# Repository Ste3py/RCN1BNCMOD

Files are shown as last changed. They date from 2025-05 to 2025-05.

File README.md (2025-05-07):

# RCN1BNCMOD

This project is about replacing the original antenna with a BNC connector on the DJI RCN1 (not tested on RCN3).



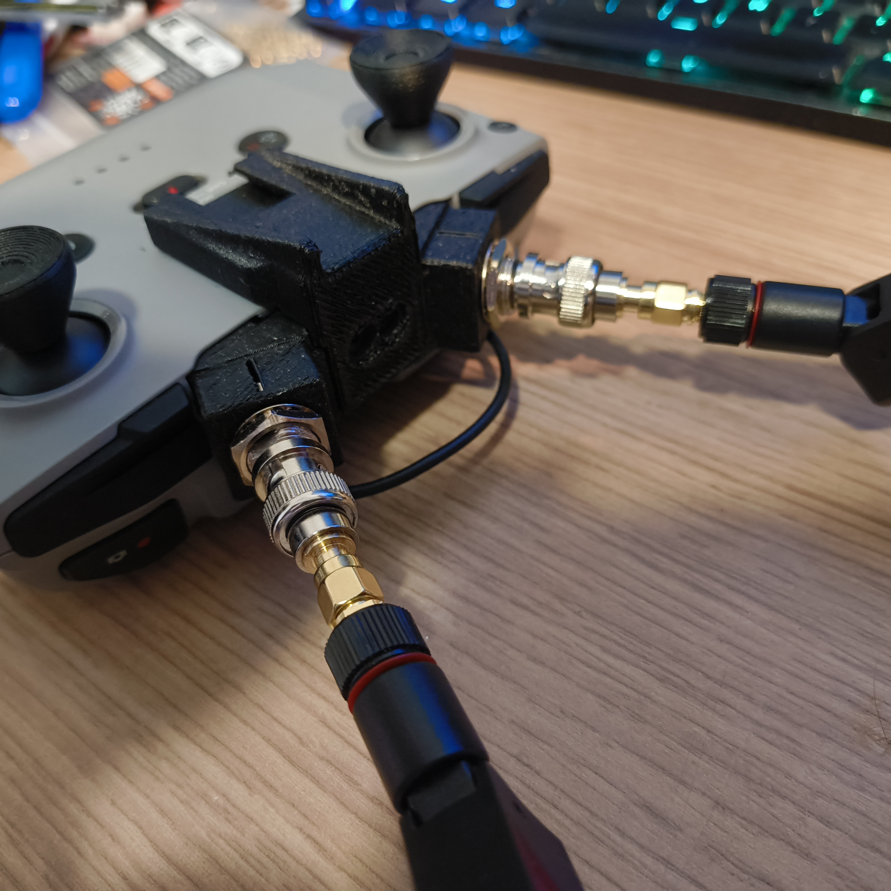
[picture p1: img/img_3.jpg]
RCN1_1
 
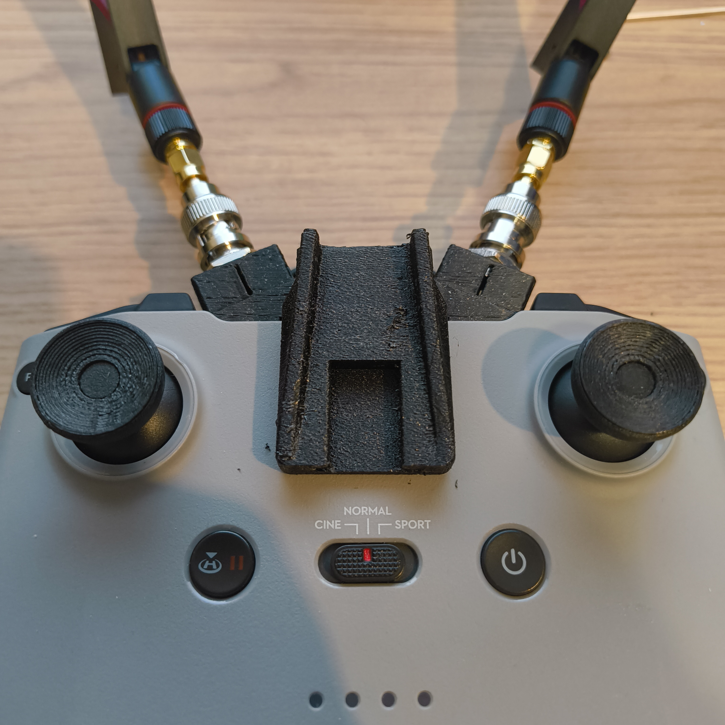
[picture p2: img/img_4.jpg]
RCN1_2


Parts needed (no Affiliate links) :
- [Cable](https://aliexpress.com/item/1005003822770662.html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)
- [tools](https://www.ifixit.com/fr-fr/products/pro-tech-go-toolkit)
- [Heated inserts M3*4mm](https://www.ruthex.de/en/collections/gewindeeinsatze/products/ruthex-gewindeeinsatz-m3-100-stuck-made-for-voron-rx-m3x5x4-messing-gewindebuchsen-fur-3d-druck)
- [M3*5 FLat head screws (7)](https://aliexpress.com/item/1005007798633538.html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)
- Filament (any filament is fine, but I recommend PETG or PETG-CF)
- a 3D Printer
- a Drill
- a 2.8mm drill bit

Antenna Side 
- [BNC Male to RP SMA](https://aliexpress.com/item/1005007758452385.html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)
- [Antenna](https://alfa-network.eu/apa-m25) (Any Wi-Fi antenna should work — just make sure it supports both 2.4 GHz and 5.8 GHz bands)

🛑 Disclaimer:
I won’t cover how to open the RCN1 here, because disassembly will void your warranty.
However, I will show you how to install the mod once it’s open.

1️⃣ Once the controller is open, disconnect the joysticks.

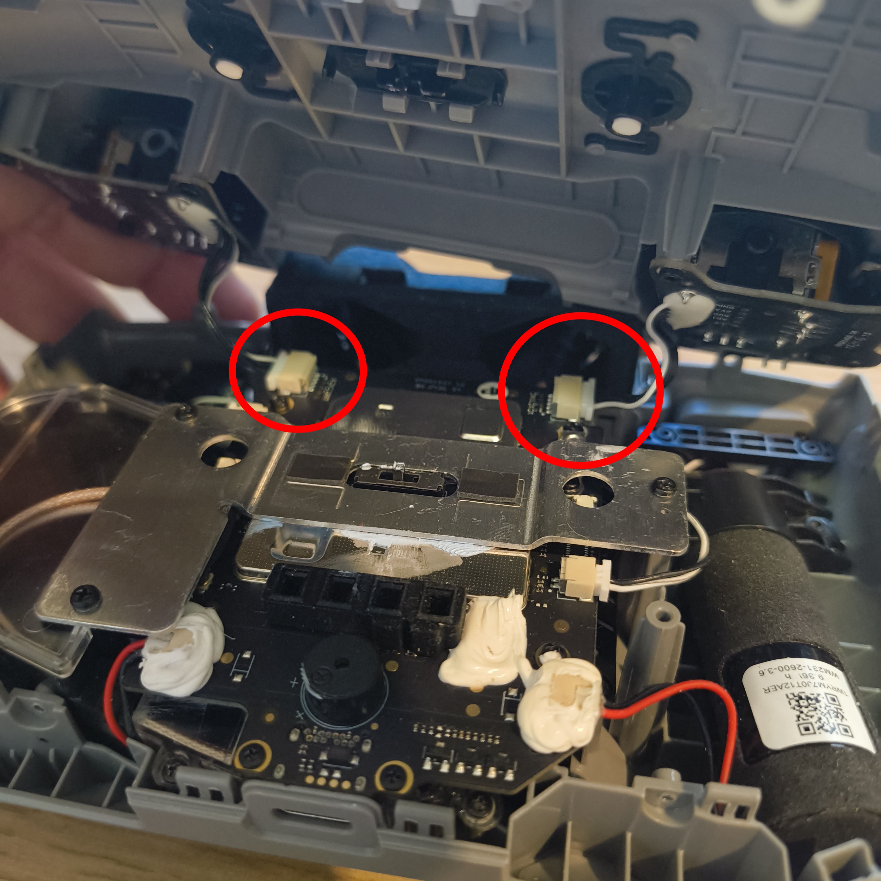
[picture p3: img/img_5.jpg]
RCN1JOYSTICK


2️⃣ Unscrew these three screws.

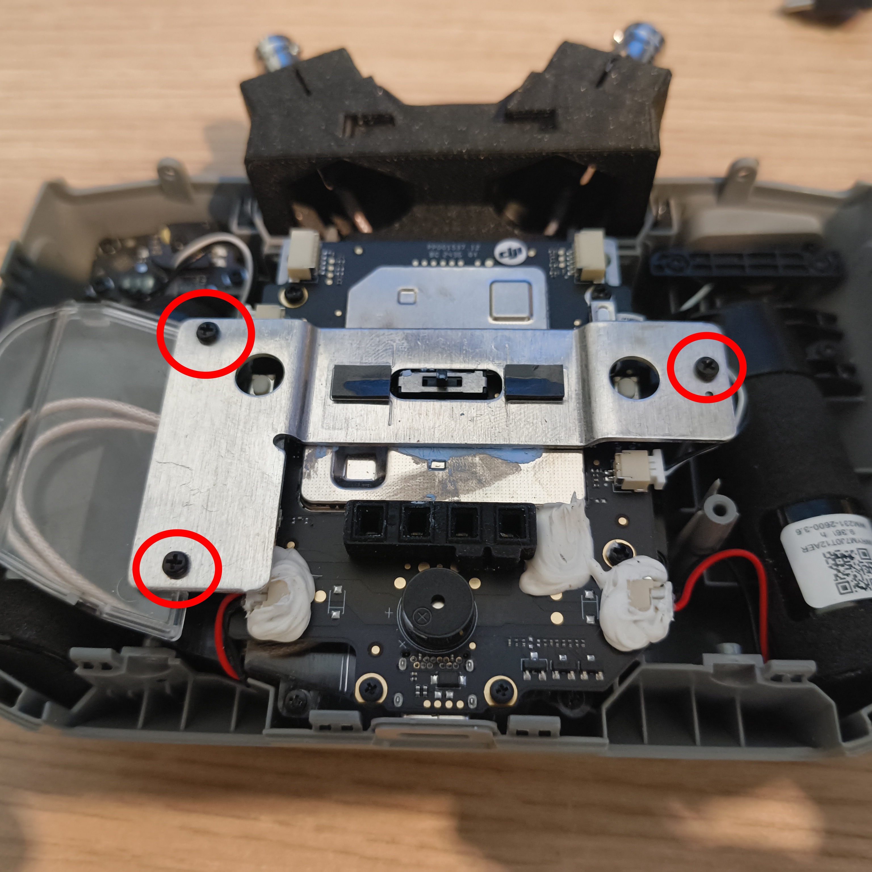
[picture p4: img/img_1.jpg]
RCN1screw


3️⃣ You now have access to the PCB.
(Ignore the modded state of my controller. I’ve already done the mod and don’t have a second RCN1 to show from scratch. The process is the same.)
Disconnect all connectors and remove the screws.
Remove the batteries first.
Be careful with the flex connector under the cage.

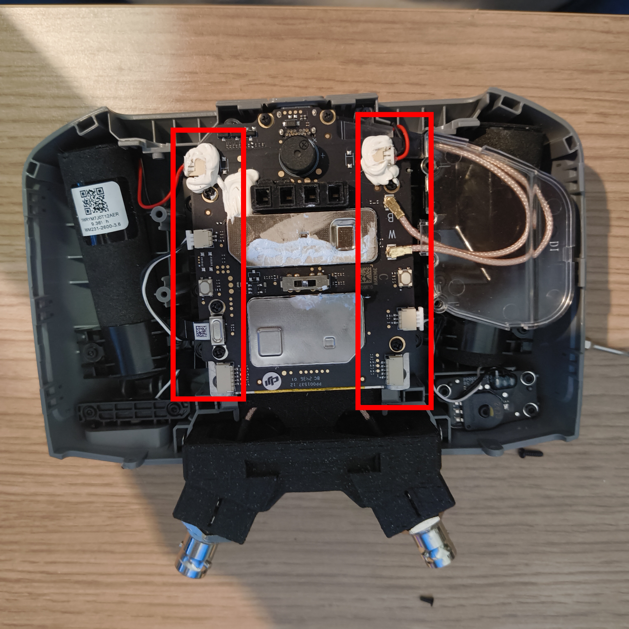
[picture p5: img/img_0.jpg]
RCN1MB


4️⃣ Remove the motherboard.
Then unscrew these two screws and remove the two transparent parts.

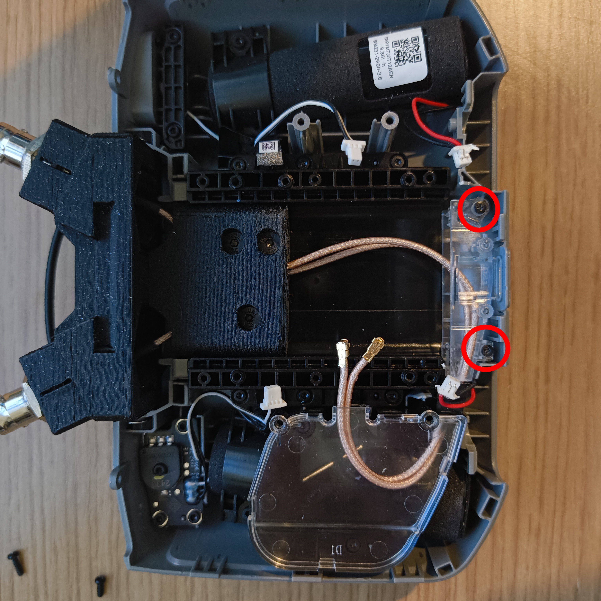
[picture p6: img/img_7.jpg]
RCN1COVER


At this point, your setup should look similar to mine, except you'll still have the original antenna attached.

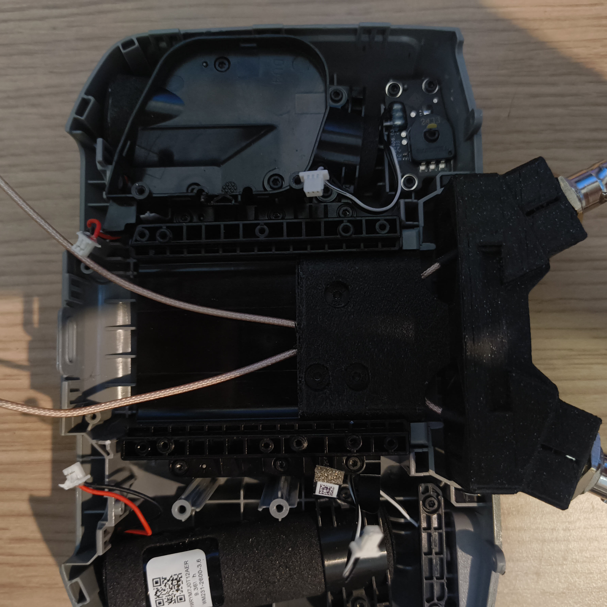
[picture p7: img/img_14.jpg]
RCN1naked


5️⃣ Remove the antenna holder by unscrewing these six screws.

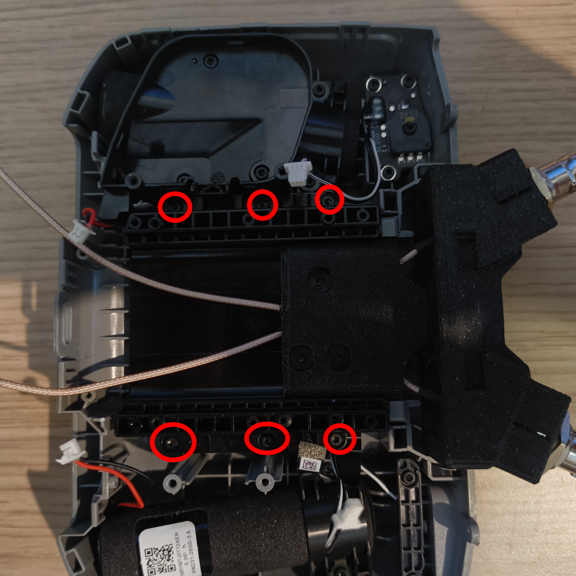
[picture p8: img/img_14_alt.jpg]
RCN1nakedalt


Now you have this piece out:

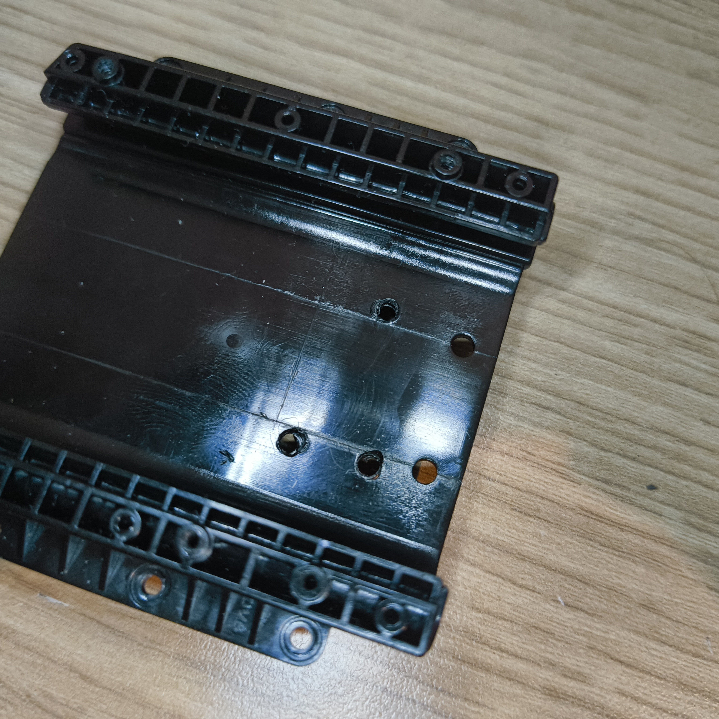
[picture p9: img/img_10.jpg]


Place it back **without screwing it in**.

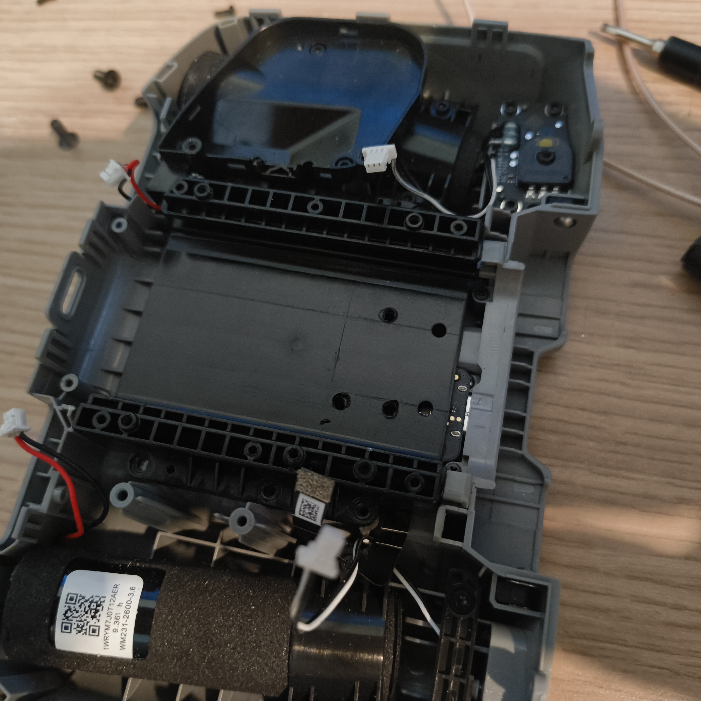
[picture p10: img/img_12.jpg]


**Assembling the BNC Connector**
6️⃣ Install the heated insert into the main part, then mount the BNC connector.

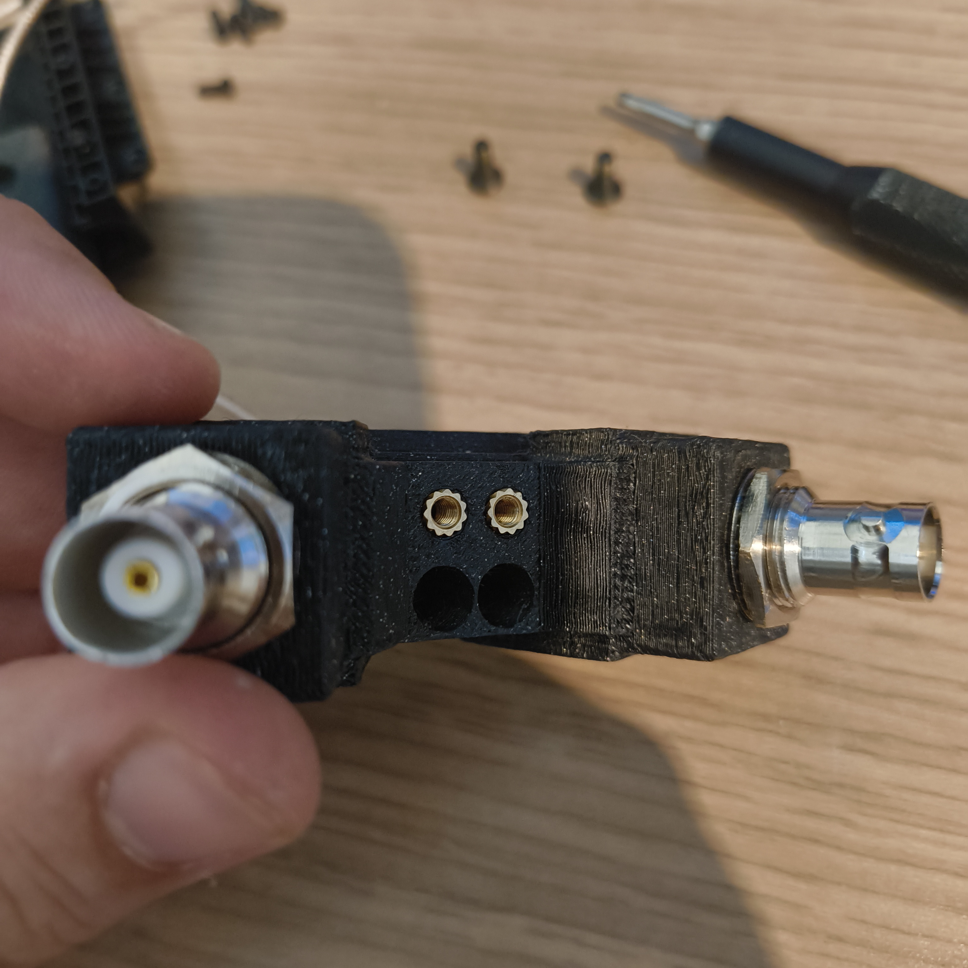
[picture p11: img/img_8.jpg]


7️⃣ On the internal support, install the heated insert and pass the cables through the holes.
It’s a bit tedious, but there’s enough space. Just be gentle to avoid damaging the connectors.

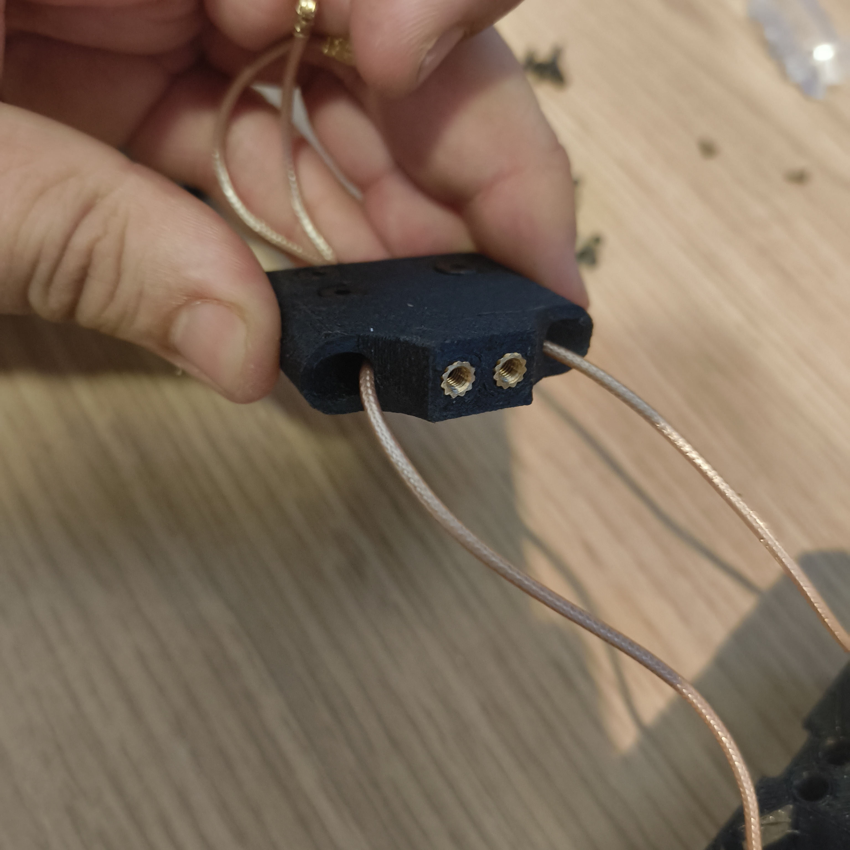
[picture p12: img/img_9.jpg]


8️⃣ Assemble both parts using two M3*5 screws in these holes.

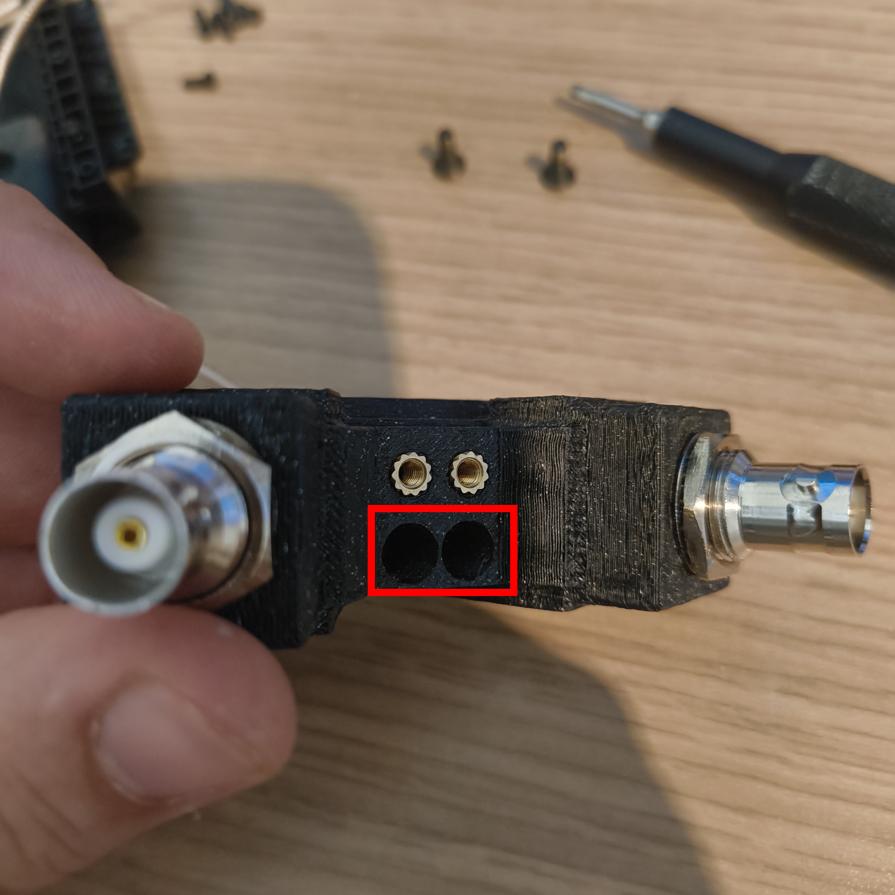
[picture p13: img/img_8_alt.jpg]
RCN1BNC2


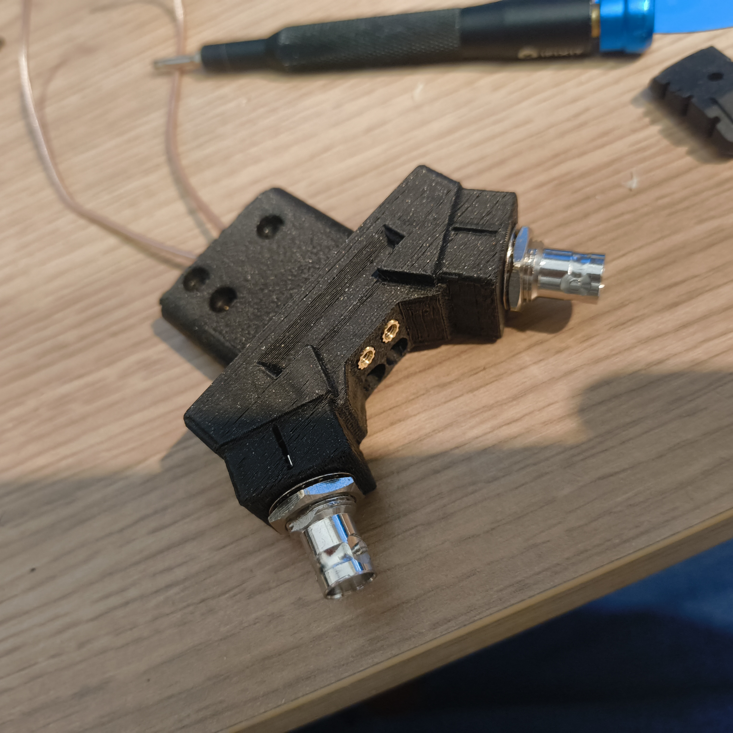
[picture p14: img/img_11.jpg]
RCN1BNC3


9️⃣ Slide the BNC assembly into the holder.

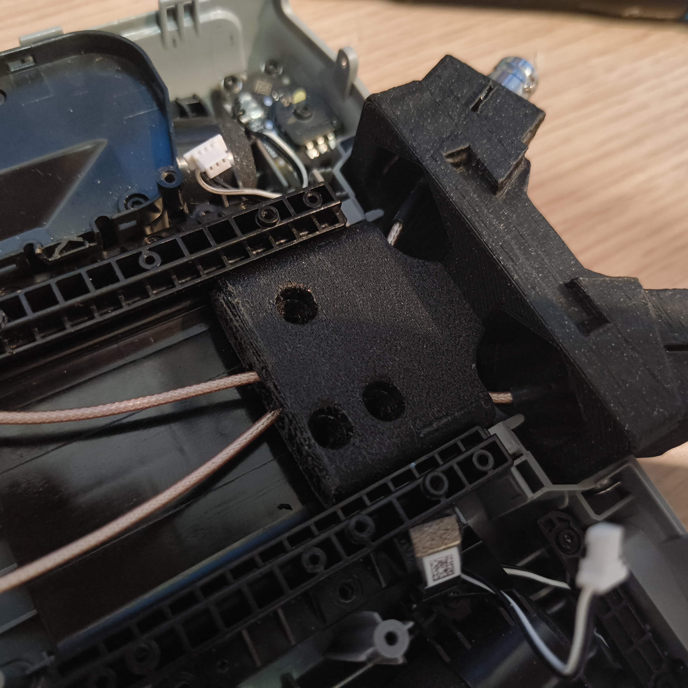
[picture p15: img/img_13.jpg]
RCN1BNC4


🔟 Mark the three small holes using the 2.8mm drill bit by hand.

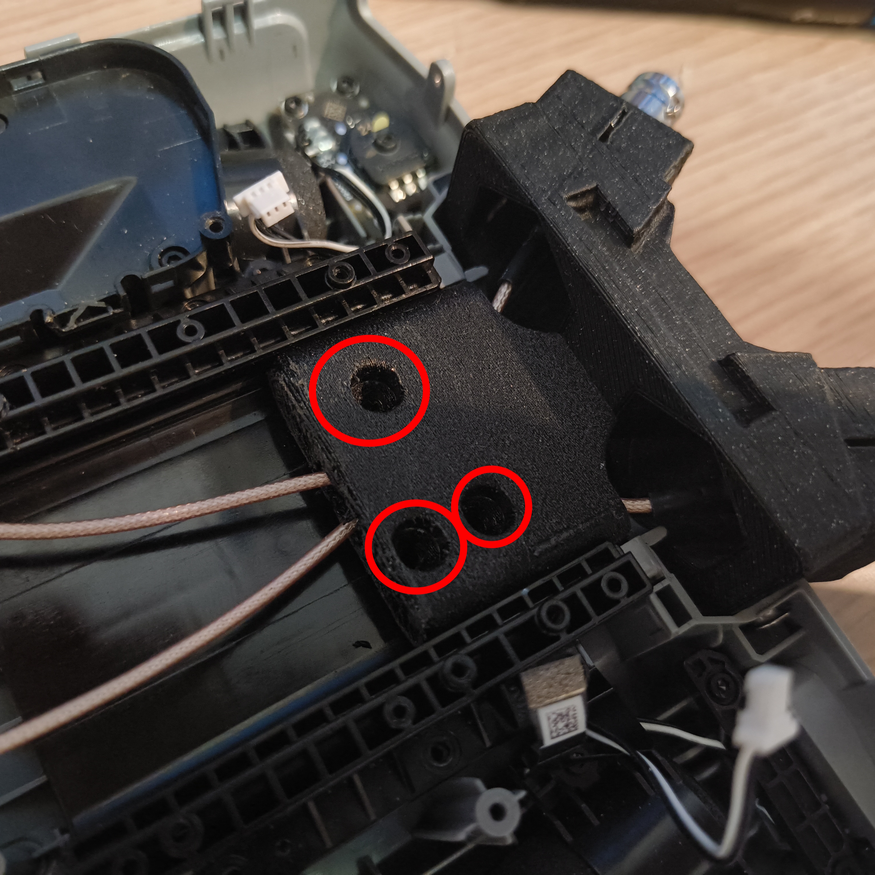
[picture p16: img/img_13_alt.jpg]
RCN1BNC5


1️⃣1️⃣ Remove everything and drill the holes properly.
Then use a screw to cut threads into the plastic and secure everything into place with the original screws and 3 M3*5 screws.

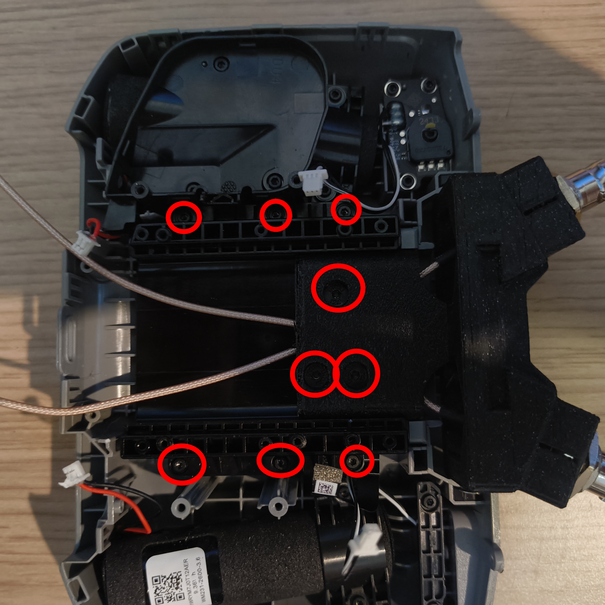
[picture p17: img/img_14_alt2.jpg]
RCN1BNC6


1️⃣2️⃣ Route the cables as shown.
You may need to trim some plastic from the transparent parts to accommodate the thicker cables.

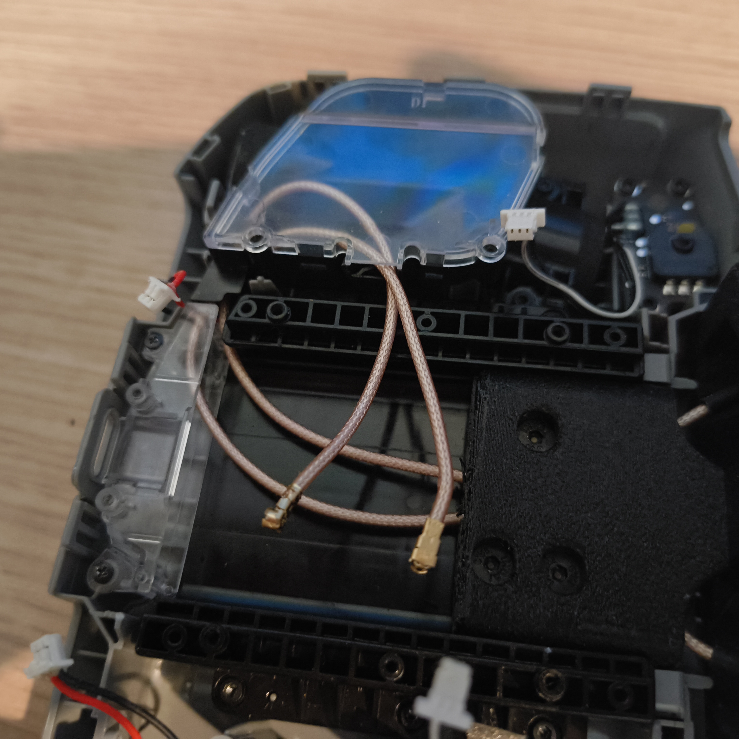
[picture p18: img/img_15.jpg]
RCN1BNC7


1️⃣3️⃣ Reassemble everything.
Note: there’s no special place for the U.FL connector — route it carefully.

⚠ Don’t forget to connect the antenna before powering on the controller!

Shield: [][cc-by-nc-sa]

This work is licensed under a
[Creative Commons Attribution-NonCommercial-ShareAlike 4.0 International License][cc-by-nc-sa].

[][cc-by-nc-sa]

[cc-by-nc-sa]: http://creativecommons.org/licenses/by-nc-sa/4.0/
[cc-by-nc-sa-image]: https://licensebuttons.net/l/by-nc-sa/4.0/88x31.png
[cc-by-nc-sa-shield]: https://img.shields.io/badge/License-CC%20BY--NC--SA%204.0-lightgrey.svg

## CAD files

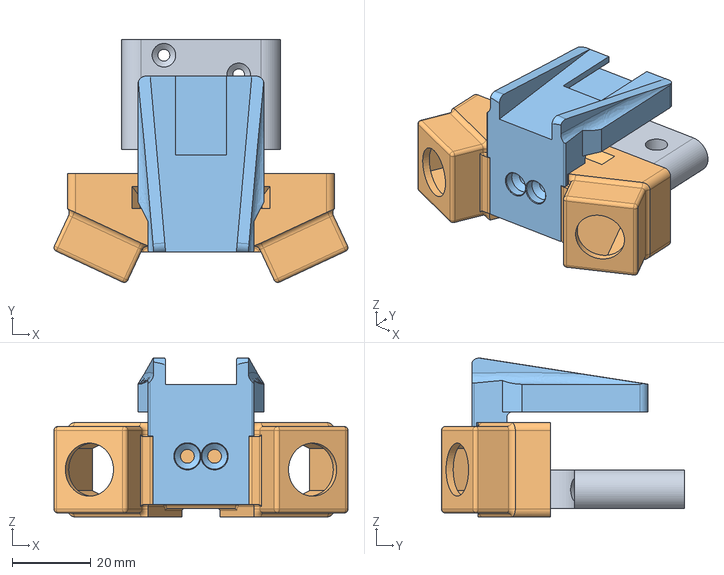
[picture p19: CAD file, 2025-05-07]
src/Mod RCN1 v21.step
74.7 x 61.8 x 40.4 mm

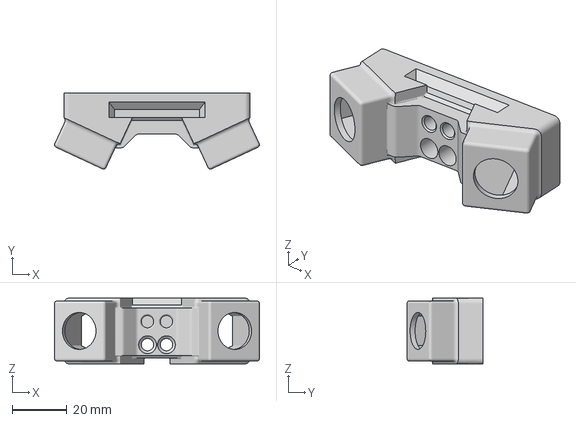
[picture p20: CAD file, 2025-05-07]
stl/BNC support.3mf
74.7 x 27.8 x 24.0 mm

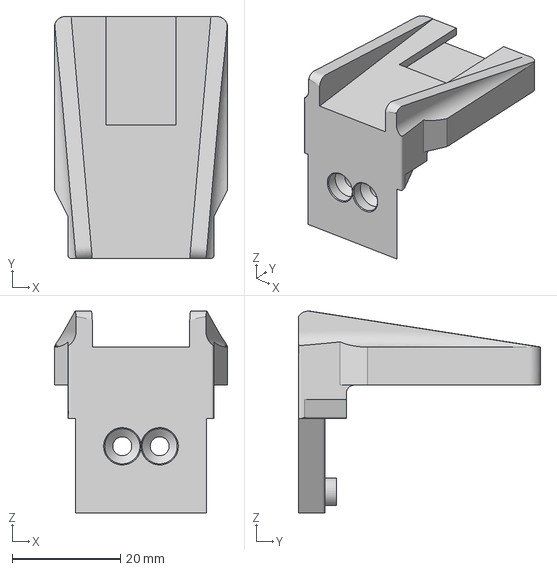
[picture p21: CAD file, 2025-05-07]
stl/hot shoe support.3mf
32.0 x 44.7 x 37.3 mm

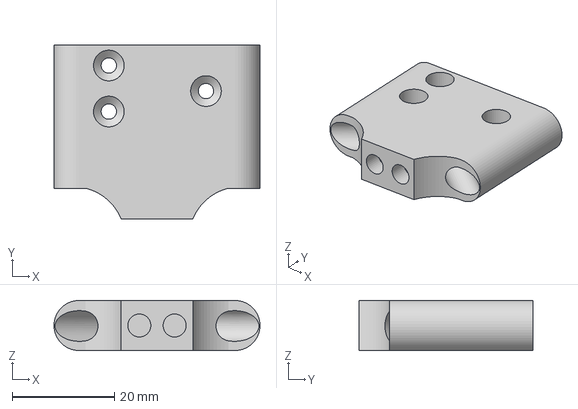
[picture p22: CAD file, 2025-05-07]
stl/internal support.3mf
40.3 x 34.0 x 9.80 mm

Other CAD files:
src/Mod RCN1 v21.f3d

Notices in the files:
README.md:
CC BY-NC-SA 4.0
